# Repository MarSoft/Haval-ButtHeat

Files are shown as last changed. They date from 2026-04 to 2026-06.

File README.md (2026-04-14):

Butt Heat Controller
====================

Custom controller for Haval Dargo's seat heaters (and A/C in the future).

Hardware and connections
------------------------

This shall run on ESP32C3 board with TJA1050 (5V power supply) or similar module
Connect to 5V supply and BD-CAN-1 (see the schematics).

Controls: two rotary encoders (left and right A/C control, click -> seat heat control, long press -> seat memory recall)
and SSD1306 0.91" 128x32 tiny display which fits above the "MODE" knob in the car.

Logic
-----

1. Listen for 2D1#00xx000000000000 messages, where `xx` is a heater status byte. They come like 10 per second.
2. Control: send 36D#00yy200000000040, where yy is a heater status *with offset*.
3. After sending a message, do not change internal state for external messages for e.g. 500ms, so that the machine will have time to react.
4. Bus error state: show "spinner" with LEDs.

Tasks:

1. Bus RX. Also responsible for bus reconnects?
2. Bus TX. Not sure if it is really required though.
3. Router task. Gets events from rotary-encoder queue (the driver uses single queue for everything) and routes them to the respective tasks.
4. Button and rotary encoders input. Also sends CAN msgs? One task per button and per encoder. Each task gets events from both input and can and is responsible for interpreting them and notifying the display.
5. Display output task.

Communication:
RX -> Button (separate task per each)
Button -> TX (or just send directly?)
Button -> Display
RX -> Display (error state)

Types:
- ac_temp_t (LO, HI, unknown, half-degrees)
- butt_temp_t (0, 1, 2, 3, unknown)

States:
1. Loading, or bus error. Spinner. Denoted by spinner_sem taken by non-LED task.
2. Normal: show info based on led_from_can_queue.
3. Input (250ms after button press): show info based on led_from_btn_queue

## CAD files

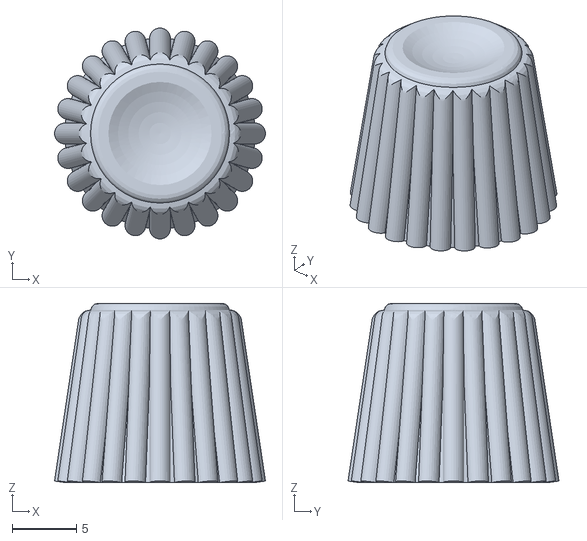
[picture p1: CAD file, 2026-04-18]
case/Knob3.stl
16.4 x 16.4 x 13.9

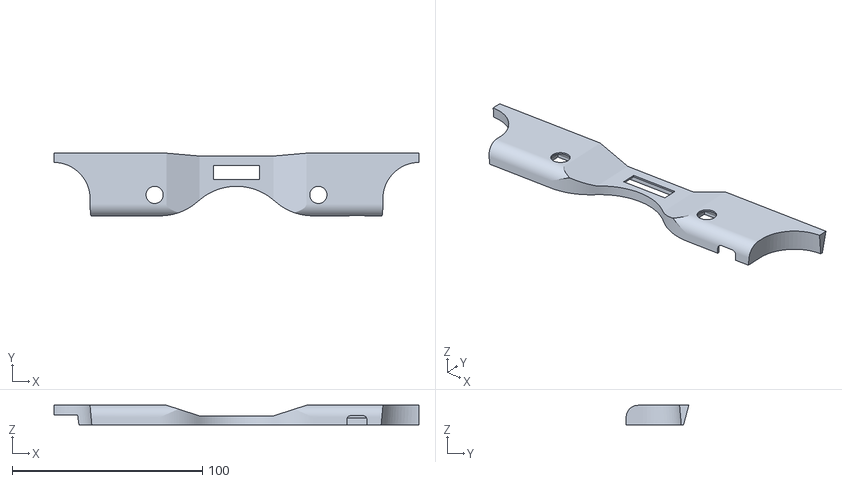
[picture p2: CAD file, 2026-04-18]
case/CaseCover6.stl
191.7 x 32.9 x 10.2

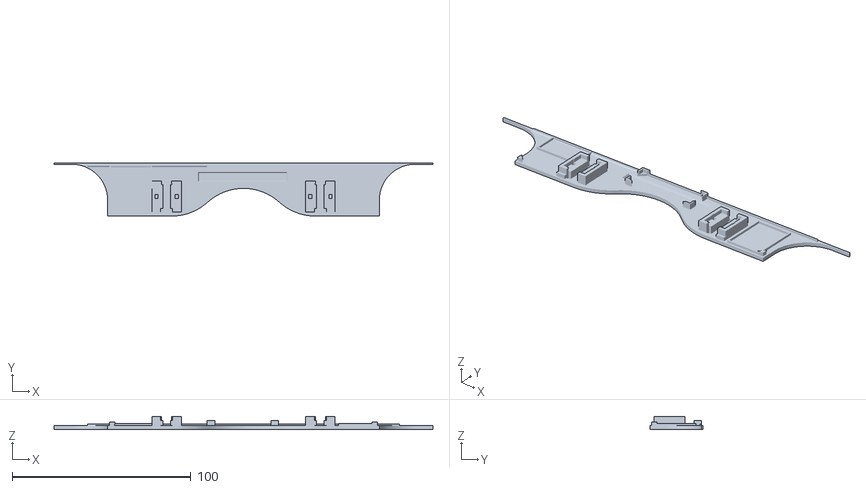
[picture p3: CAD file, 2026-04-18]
case/CaseBase5.stl
212.0 x 29.8 x 7.00

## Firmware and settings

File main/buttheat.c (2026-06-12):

/*
 * SPDX-FileCopyrightText: 2010-2024 Espressif Systems (Shanghai) CO LTD
 *
 * SPDX-License-Identifier: CC0-1.0
 */

/*
 * The following example demonstrates a slave node in a TWAI network. The slave
 * node is responsible for sending data messages to the master. The example will
 * execute multiple iterations, with each iteration the slave node will do the
 * following:
 * 1) Start the TWAI driver
 * 2) Listen for ping messages from master, and send ping response
 * 3) Listen for start command from master
 * 4) Send data messages to master and listen for stop command
 * 5) Send stop response to master
 * 6) Stop the TWAI driver
 */

#include <stdio.h>
#include <stdlib.h>
#include <string.h>
#include "freertos/FreeRTOS.h"
#include "freertos/projdefs.h"
#include "freertos/task.h"
#include "freertos/queue.h"
#include "freertos/semphr.h"
#include "esp_err.h"
#include "esp_log.h"
#include "esp_twai.h"
#include "esp_twai_onchip.h"
#include "hal/i2c_types.h"
#include "portmacro.h"

#include "esp_timer.h"
#include "sdkconfig.h"
#include "ssd1306.h"
#include "font16x28.h"  // generated with tools/gen_font16x28.py
#include "encoder.h"

/* --------------------- Definitions and static variables ------------------ */
//Example Configuration
#define TAG "ButtHeat"

typedef int32_t rotary_value_t;

typedef uint8_t ac_temp_t;  // 0 = LO; 1 = 16.5; 2 = 17; ...; 30=31; 31=31.5; 32=HI
#define AC_TEMP_HI 32
#define AC_TEMP_MAX 31
#define AC_TEMP_MIN 1
#define AC_TEMP_LO 0
// ac to degrees: (val / 2) + 16

typedef uint8_t fan_speed_t;
#define FAN_SPEED_UNKNOWN 0
// fan-off requires special handling
#define FAN_SPEED_OFF 0
#define FAN_SPEED_MIN 1
#define FAN_SPEED_MAX 7

// Airflow direction from 0x29D byte[2]: (upper_nibble >> 1)
// Raw upper nibble: 0=face, 2=face+feet, 4=feet, 6=feet+windshield, 8=windshield, E=off
typedef enum {
    AIRFLOW_FACE = 0,            // head/face vents
    AIRFLOW_FACE_FEET = 1,      // face + feet
    AIRFLOW_FEET = 2,            // feet only
    AIRFLOW_FEET_WINDSHIELD = 3, // feet + windshield defrost
    AIRFLOW_WINDSHIELD = 4,      // windshield only (defrost)
    AIRFLOW_OFF = 7,             // AC off (raw 0xE >> 1)
} airflow_dir_t;
#define AIRFLOW_FROM_CAN(b)  ((airflow_dir_t)((b) >> 5))  // extract from 0x29D byte[2]

// positive 1..3: heater, negative -1..-3: fan
typedef int8_t butt_temp_t;

typedef enum {
    MASSAGE_MODE_WAVES = 0,
    MASSAGE_MODE_DOTS = 1,
    MASSAGE_MODE_GENERAL = 2,
    MASSAGE_MODE_SHOULDER = 3,
    MASSAGE_MODE_WAIST = 4,
} massage_mode_t;

// Massage state. Layout is provisional and will change once the real CAN
// payload is decoded; do not rely on bit positions for wire serialization.
typedef struct {
    uint8_t intensity : 2;  // 0=off, 1..3
    uint8_t mode      : 3;  // massage_mode_t
    uint8_t _pad      : 3;
} __attribute__((packed)) massage_t;
#define MASSAGE_IS_OFF(m) ((m).intensity == 0)

typedef union {
    ac_temp_t ac;
    fan_speed_t fan;
    airflow_dir_t airflow;
    butt_temp_t butt;
    massage_t massage;
    uint8_t _max; // for simpler equality check
} union_temp_t;

typedef enum {
    HANDLER_TYPE_AC,
    HANDLER_TYPE_FAN,
    HANDLER_TYPE_AIRFLOW,
    HANDLER_TYPE_BUTTHEAT,
    HANDLER_TYPE_MASSAGE,
} handler_type_t;

typedef struct {
    handler_type_t type;
    QueueHandle_t control_queue; // capacity: 8, since we don't want to lost those msgs!
    QueueHandle_t can_queue; // capacity: 1, and new message overwrites existing one.
    bool leftside;
} handler_config_t;

typedef enum {
    DU_BUTTHEAT,
    DU_AC,
    DU_DISABLE_TWOZONE, // toggle two-zone AC off (only if currently on)
    DU_FANSPEED,
    DU_AIRFLOW,
    DU_MASSAGE,
    DU_SEAT_MEMORY,
    DU_CAN_ERROR, // put display to "can error" state
    DU_LONGPRESS_STAGE,    // overlay while holding: seat_mem_slot 0=clear, 1-3=slot
    DU_LONGPRESS_CONFIRM,  // confirmed on release: seat_mem_slot 1-3, triggers blink
    DU_AC_ACK,             // AC controller ack bit changed (leftside = new value)
} data_update_kind_t;
typedef struct {
    data_update_kind_t kind;
    bool leftside;
    union {
        ac_temp_t ac_temp;
        fan_speed_t fan_speed;
        airflow_dir_t airflow_dir;
        butt_temp_t butt_temp;
        massage_t massage;
        uint8_t seat_mem_slot;
        bool ac_ack;
    };
} data_update_t;

#define CAN_ID_HEATER_STATUS 0x2D1
#define CAN_ID_HEATER_CONTROL 0x36D
#define CAN_ID_FAN_CONTROL 0x367
#define CAN_ID_AIRFLOW_STATUS 0x29D
#define CAN_ID_AC_STATUS 0x385
#define CAN_ID_AC_CONTROL 0x1EE
#define CAN_ID_SEAT_MEMORY 0x1ED
// TODO: real ID + filter wiring once the bus has been observed.
#define CAN_ID_MASSAGE_STATUS 0x000

// RX message struct for ISR → task queue transfer
typedef struct {
    uint32_t id;
    uint8_t data[8];
    uint8_t dlc;
} rx_can_msg_t;

static twai_node_handle_t twai_node;
static QueueHandle_t twai_rx_queue;

static handler_config_t left_ac_handler = {
    .type = HANDLER_TYPE_AC,
    .leftside = true,
};
static handler_config_t right_ac_handler = {
    .type = HANDLER_TYPE_AC,
    .leftside = false,
};
static handler_config_t fan_speed_handler = {
    .type = HANDLER_TYPE_FAN,
};
static handler_config_t airflow_handler = {
    .type = HANDLER_TYPE_AIRFLOW,
};
static handler_config_t left_butt_handler = {
    .type = HANDLER_TYPE_BUTTHEAT,
    .leftside = true,
};
static handler_config_t right_butt_handler = {
    .type = HANDLER_TYPE_BUTTHEAT,
    .leftside = false,
};
// Driver-side massage only; no right-seat counterpart on this vehicle.
static handler_config_t massage_handler = {
    .type = HANDLER_TYPE_MASSAGE,
    .leftside = true,
};

static QueueHandle_t tx_task_queue;
static QueueHandle_t display_queue;
static SemaphoreHandle_t done_sem;
static bool twozone_active = false; // updated by twai_receive_task, read by twai_transmit_task
static bool ac_just_updated = false; // set by twai_receive_task when AC controller acks a change
static fan_speed_t current_fan_speed = 0; // updated by twai_receive_task

/* --------------------------- Tasks and Functions -------------------------- */

static IRAM_ATTR bool twai_state_change_isr_cb(twai_node_handle_t handle,
                                                const twai_state_change_event_data_t *edata,
                                                void *user_ctx)
{
    if(edata->new_sta == TWAI_ERROR_BUS_OFF) {
        twai_node_recover(handle);
    }
    return false;
}

static IRAM_ATTR bool twai_rx_isr_cb(twai_node_handle_t handle,
                                       const twai_rx_done_event_data_t *edata,
                                       void *user_ctx)
{
    QueueHandle_t rx_queue = (QueueHandle_t)user_ctx;
    uint8_t buf[8];
    twai_frame_t frame = { .buffer = buf, .buffer_len = sizeof(buf) };
    if(twai_node_receive_from_isr(handle, &frame) == ESP_OK) {
        rx_can_msg_t msg = { .id = frame.header.id, .dlc = frame.header.dlc };
        memcpy(msg.data, buf, sizeof(buf));
        BaseType_t woken = pdFALSE;
        xQueueSendFromISR(rx_queue, &msg, &woken);
        return woken == pdTRUE;
    }
    return false;
}

#ifdef CAN_DEBUG
// Per-CAN-ID cache for debug change-detection. Small fixed table keyed by ID;
// linear scan is fine — we filter aggressively so only a handful of IDs reach us.
typedef struct {
    uint32_t id;
    uint8_t data[8];
    bool valid;
} can_cache_entry_t;

static bool can_data_changed(uint32_t id, const uint8_t *data) {
    static can_cache_entry_t cache[8] = {0};
    static int n_entries = 0;
    uint8_t size = 8, offset = 0;
    if(id == CAN_ID_AC_STATUS || id == 0x295) {
        // ignore first and last bytes when they are some counters/checksums
        offset = 1;
        size = 6;
    }
    for(int i = 0; i < n_entries; i++) {
        if(cache[i].id == id) {
            if(memcmp(cache[i].data+offset, data+offset, size) == 0) return false;
            memcpy(cache[i].data+offset, data+offset, size);
            return true;
        }
    }
    if(n_entries < (int)(sizeof(cache) / sizeof(cache[0]))) {
        cache[n_entries].id = id;
        memcpy(cache[n_entries].data, data, 8);
        cache[n_entries].valid = true;
        n_entries++;
    }
    return true; // first time we see this ID — log it
}
#endif

static void twai_receive_task(void *arg)
{
    bool prev_ac_ack = false;
    while (1) {
        rx_can_msg_t rx_msg;
        if(xQueueReceive(twai_rx_queue, &rx_msg, pdMS_TO_TICKS(500)) != pdTRUE) {
            ESP_LOGW(TAG, "TWAI recv timeout");
            data_update_t err_msg = { .kind = DU_CAN_ERROR };
            xQueueSend(display_queue, &err_msg, 0);
            continue;
        }
        if (rx_msg.dlc != 8) {
            ESP_LOGI(TAG, "TWAI recv unexpected len %d", rx_msg.dlc);
            continue;
        }
#ifdef CAN_DEBUG
        if(can_data_changed(rx_msg.id, rx_msg.data)) {
            ESP_LOGI(TAG, "CAN 0x%03lX: %02X %02X %02X %02X %02X %02X %02X %02X",
                     (unsigned long)rx_msg.id,
                     rx_msg.data[0], rx_msg.data[1], rx_msg.data[2], rx_msg.data[3],
                     rx_msg.data[4], rx_msg.data[5], rx_msg.data[6], rx_msg.data[7]);
        }
#endif
        switch(rx_msg.id) {
            case CAN_ID_HEATER_STATUS:
                // parse message
                uint8_t b = rx_msg.data[1];  // the only meaningful byte
                // data structure of this byte:
                // LLRRllrr, where L/R is heater and l/r is fan
                butt_temp_t butt_left = b >> 6;
                butt_temp_t butt_right = (b >> 4) & 0b11;

                uint8_t butt_fan_left = (b >> 2) & 0b11;
                uint8_t butt_fan_right = b & 0b11;

                if(butt_fan_left > 0) {
                    butt_left = -butt_fan_left;
                }
                if(butt_fan_right > 0) {
                    butt_right = -butt_fan_right;
                }

                // send to the queue, overwrite any stale value
                xQueueOverwrite(left_butt_handler.can_queue, &butt_left);
                xQueueOverwrite(right_butt_handler.can_queue, &butt_right);
                break;
            case CAN_ID_AC_STATUS:
                // parse message
                // example:
                //        __ changes from 41 to 61 for 1sec when the value is changed?
                //      /          __ left
                //     |         /     __ right
                //     v        v     v
                // F6 41 6C C8 C0 02 C0 36
                ac_temp_t ac_left = (rx_msg.data[4] >> 1) & 0x3f;
                ac_temp_t ac_right = (rx_msg.data[6]) & 0x3f;
                twozone_active = (rx_msg.data[4] & 0x80) != 0;
                ac_just_updated = (rx_msg.data[1] & 0x20) != 0;
                if(ac_just_updated != prev_ac_ack) {
                    prev_ac_ack = ac_just_updated;
                    data_update_t ack_msg = {
                        .kind = DU_AC_ACK,
                        .ac_ack = ac_just_updated,
                    };
                    xQueueSend(display_queue, &ack_msg, 0);
                }
                fan_speed_t fan_speed = rx_msg.data[1] & 7;
                current_fan_speed = fan_speed;
                // if(rx_msg.data[1] == 0) then fan is off
                // int cur_temp_in_cabin_info = rx_msg.data[3]? variants:
                // bool ac_on = rx_msg.data[5] & 0x8 != 0
                // bool air_from_outside_taken = rx_msg.data[5] & 0x2 != 0
                // bool windshield_heat = rx_msg.data[5] & 0x10 != 0
                xQueueOverwrite(left_ac_handler.can_queue, &ac_left);
                xQueueOverwrite(right_ac_handler.can_queue, &ac_right);
                xQueueOverwrite(fan_speed_handler.can_queue, &fan_speed);
                break;
            case CAN_ID_AIRFLOW_STATUS:
                airflow_dir_t airflow = AIRFLOW_FROM_CAN(rx_msg.data[2]);
                xQueueOverwrite(airflow_handler.can_queue, &airflow);
                break;
            case CAN_ID_MASSAGE_STATUS:
                // TODO: real parse once the bus layout is known. For now produce
                // an "off" value so the wiring exercises end-to-end.
                massage_t massage = { .intensity = 0, .mode = 0 };
                xQueueOverwrite(massage_handler.can_queue, &massage);
                break;
            default:
                // unsupported message, ignore
                break;
        }
    }
    vTaskDelete(NULL);
}

// Ensure fan is running before sending AC commands.
// Sends fan speed 1 and waits for confirmation (~60ms retry, up to 10 attempts).
static void ensure_fan_on(uint8_t *fan_data, twai_frame_t *msg_fan_set) {
    if(current_fan_speed != FAN_SPEED_OFF) return;

    ESP_LOGI(TAG, "Fan is off, turning on (speed 1) before AC command");
    for(int i = 0; i < 10 && current_fan_speed == FAN_SPEED_OFF; i++) {
        fan_data[7] = FAN_SPEED_MIN;
        twai_node_transmit(twai_node, msg_fan_set, -1);
        fan_data[7] = 0;
        vTaskDelay(pdMS_TO_TICKS(60));
    }
    if(current_fan_speed == FAN_SPEED_OFF) {
        ESP_LOGW(TAG, "Fan did not turn on after retries, proceeding anyway");
    }
}
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
void app_main(void)
{
    //Create semaphores and tasks
    tx_task_queue = xQueueCreate(8, sizeof(data_update_t));
    display_queue = xQueueCreate(8, sizeof(data_update_t));
    left_ac_handler.control_queue = xQueueCreate(8, sizeof(rotary_value_t));
    left_ac_handler.can_queue = xQueueCreate(1, sizeof(ac_temp_t));
    right_ac_handler.control_queue = xQueueCreate(8, sizeof(rotary_value_t));
    right_ac_handler.can_queue = xQueueCreate(1, sizeof(ac_temp_t));
    fan_speed_handler.control_queue = xQueueCreate(8, sizeof(rotary_value_t));
    fan_speed_handler.can_queue = xQueueCreate(1, sizeof(fan_speed_t));
    airflow_handler.control_queue = xQueueCreate(8, sizeof(rotary_value_t));
    airflow_handler.can_queue = xQueueCreate(1, sizeof(airflow_dir_t));
    left_butt_handler.control_queue = xQueueCreate(8, sizeof(uint8_t));
    left_butt_handler.can_queue = xQueueCreate(1, sizeof(butt_temp_t));
    right_butt_handler.control_queue = xQueueCreate(8, sizeof(uint8_t));
    right_butt_handler.can_queue = xQueueCreate(1, sizeof(butt_temp_t));
    massage_handler.control_queue = xQueueCreate(8, sizeof(rotary_value_t));
    massage_handler.can_queue = xQueueCreate(1, sizeof(massage_t));
    done_sem  = xSemaphoreCreateBinary();

    // TWAI node init (new driver API)
    twai_rx_queue = xQueueCreate(8, sizeof(rx_can_msg_t));
    twai_onchip_node_config_t node_config = {
        .io_cfg = {
            .tx = CONFIG_TX_GPIO_NUM,
            .rx = CONFIG_RX_GPIO_NUM,
            .quanta_clk_out = GPIO_NUM_NC,
            .bus_off_indicator = GPIO_NUM_NC,
        },
        .bit_timing = { .bitrate = 500000 },
        .tx_queue_depth = 5,
        .fail_retry_cnt = -1,  // retry forever
    };
    ESP_ERROR_CHECK(twai_new_node_onchip(&node_config, &twai_node));
    ESP_ERROR_CHECK(twai_node_register_event_callbacks(twai_node, &(twai_event_callbacks_t){
        .on_rx_done = twai_rx_isr_cb,
        .on_state_change = twai_state_change_isr_cb,
    }, twai_rx_queue));
    // Dual filter: exact 0x385 (AC), combined 0x2D1+0x29D (heater+airflow)
    // 0x2D1 ^ 0x29D = 0x04C (3 bits differ); accepts 8 IDs, only 0x295 extra on bus
    twai_mask_filter_config_t filter = twai_make_dual_filter(
        CAN_ID_AC_STATUS, 0x7FF,                                              // exact 0x385
        CAN_ID_HEATER_STATUS, ~(CAN_ID_HEATER_STATUS ^ CAN_ID_AIRFLOW_STATUS) & 0x7FF, // 0x2D1+0x29D
        false  // standard 11-bit IDs
    );
    ESP_ERROR_CHECK(twai_node_config_mask_filter(twai_node, 0, &filter));

    xTaskCreatePinnedToCore(twai_receive_task, "TWAI_rx", 4096, NULL, 8, NULL, tskNO_AFFINITY);
    xTaskCreatePinnedToCore(twai_transmit_task, "TWAI_tx", 4096, NULL, 9, NULL, tskNO_AFFINITY);
    xTaskCreatePinnedToCore(encoder_router_task, "ENC_router", 4096, NULL, 16, NULL, tskNO_AFFINITY);
    xTaskCreatePinnedToCore(display_task, "DISP", 4096, NULL, 10, NULL, tskNO_AFFINITY);
    xTaskCreatePinnedToCore(generic_handler_task, "AC_left", 4096, (void*)&left_ac_handler, 3, NULL, tskNO_AFFINITY);
    xTaskCreatePinnedToCore(generic_handler_task, "AC_right", 4096, (void*)&right_ac_handler, 3, NULL, tskNO_AFFINITY);
    xTaskCreatePinnedToCore(generic_handler_task, "FAN", 4096, (void*)&fan_speed_handler, 3, NULL, tskNO_AFFINITY);
    xTaskCreatePinnedToCore(generic_handler_task, "AIRFLOW", 4096, (void*)&airflow_handler, 3, NULL, tskNO_AFFINITY);
    xTaskCreatePinnedToCore(generic_handler_task, "BUTT_left", 4096, (void*)&left_butt_handler, 3, NULL, tskNO_AFFINITY);
    xTaskCreatePinnedToCore(generic_handler_task, "BUTT_right", 4096, (void*)&right_butt_handler, 3, NULL, tskNO_AFFINITY);
    xTaskCreatePinnedToCore(generic_handler_task, "MASSAGE", 4096, (void*)&massage_handler, 3, NULL, tskNO_AFFINITY);

    // Enable TWAI after all tasks are created and have set up their queue sets.
    // On single-core ESP32-C3, higher-priority tasks (handler tasks at prio 3)
    // preempt app_main (prio 1) during xTaskCreate, run until they block on
    // xQueueSelectFromSet, then return here. So by this point all queue sets
    // are ready. Enabling earlier would race: ISR→receive_task→xQueueOverwrite
    // could fill a can_queue before its handler adds it to a queue set, making
    // the item invisible to xQueueSelectFromSet forever.
    ESP_ERROR_CHECK(twai_node_enable(twai_node));
    ESP_LOGI(TAG, "TWAI node enabled");

    while(!xSemaphoreTake(done_sem, portMAX_DELAY));    //Wait for tasks to complete

    //Uninstall TWAI driver
    ESP_ERROR_CHECK(twai_node_disable(twai_node));
    ESP_ERROR_CHECK(twai_node_delete(twai_node));
    ESP_LOGI(TAG, "TWAI node deleted");

    //Cleanup
    vSemaphoreDelete(done_sem);
    vQueueDelete(tx_task_queue);
    vQueueDelete(display_queue);
}

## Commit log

2025-12-05 Update CAN and filter config
2025-12-15 Switch from LEDs to ssd1306 display
2025-12-15 Fix typos and drop redundant configs
    [buttheat.c]
2025-12-15 Add rotary encoder component
2025-12-15 Drop this rotary encoder lib as it does not support multiple encoders
2025-12-16 Impl heater control
2025-12-16 Generalize button/encoder handler
2025-12-16 Use proper queue set capacity
2025-12-16 Fix settle timeout handling logic to avoid desync of qset and queue
    [buttheat.c]
2025-12-16 Add heat lines
2025-12-16 Revert "Drop semaphores as we don't use them for now"
    This reverts commit 16eea650fcb37d273d998ce5848501c815350127.
    [buttheat.c]
2025-12-16 Special handling for edge values of temperature
2026-01-07 Fix twai recv mask
    [buttheat.c]
2026-01-07 Do not log can recv timeout errors
    [buttheat.c]
2026-01-07 Pin esp-idf for now
2026-01-07 Revert "Do not log can recv timeout errors"
    This reverts commit b68c0ad1f387e4dd76616ad1382ee0f4ba98960f.
    [buttheat.c]
2026-04-13 Support a/c temp setting and fix limits
    [buttheat.c]
2026-04-13 Fix ac temp type decl
    [buttheat.c]
2026-04-13 Fix ac parsing and do send values to the queue
    [buttheat.c]
2026-04-13 Draw dot for temperature halves
2026-04-14 Fix temp halves lbl
    [buttheat.c]
2026-04-14 Fix twai filter
2026-04-14 Fix AC left value
    [buttheat.c]
2026-04-14 Coalesce multiple events to avoid too frequent CAN transmissions
    [buttheat.c]
2026-04-18 Add STL files for the case and knobs
    [CaseBase5.stl, CaseCover6.stl, Knob3.stl]
2026-04-18 Differentiate long-press stages, use left btn for seat mem
2026-04-18 Switch to custom bitmap font
2026-04-21 WiP fan speed control
2026-04-21 Do show fan speed
2026-04-21 Treat secondary rotation as fan control
2026-04-21 Impl fan speed write
2026-04-23 Support turning fan off
2026-04-23 Draw chars to buffer to avoid flickering
    [buttheat.c]
2026-04-24 Fix intermittent AC status receive failure on boot
    Switch TWAI mode from NO_ACK to NORMAL.
    NO_ACK (self-test) mode bypasses the ESP32-C3 errata workaround
    (CONFIG_TWAI_ERRATA_FIX_LISTEN_ONLY_DOM) that forces the controller
    into error-passive state on startup. Without it, the controller joins
    the bus mid-frame in error-active state, transmits dominant active
    error frames, and can disrupt bus synchronization — causing one of the
    dual acceptance filters (typically 0x385/AC status) to fail silently.
    NORMAL mode is correct for our use case: we're on a real CAN bus with
    other nodes that provide ACKs. NO_ACK was only needed for self-test
    without other bus participants.
    [buttheat.c]
2026-04-24 Make sure fan is on before changing temperature (did not help)
    Otherwise temperature change is silently ignored
2026-04-24 bugfix: switch to single multipass filter to workaround double-filter intermittent issue
    [buttheat.c]
2026-04-24 migrate to newer twai driver
2026-04-24 More verbose can error log
    [buttheat.c]
2026-04-24 Do not start receiving can until all tasks are ready
    This is likely to permanently fix the original init-freeze bug.
    [buttheat.c]
2026-04-24 Show current airflow configuration
2026-05-25 Support displaying seat fan level
2026-05-25 Replace heat waves with bigger airflow direction icon
    [buttheat.c]
2026-05-25 CAN debug: filter first/last byte for some ids
2026-06-12 Fix emitting buttheat updates when fan is on
    [buttheat.c]
